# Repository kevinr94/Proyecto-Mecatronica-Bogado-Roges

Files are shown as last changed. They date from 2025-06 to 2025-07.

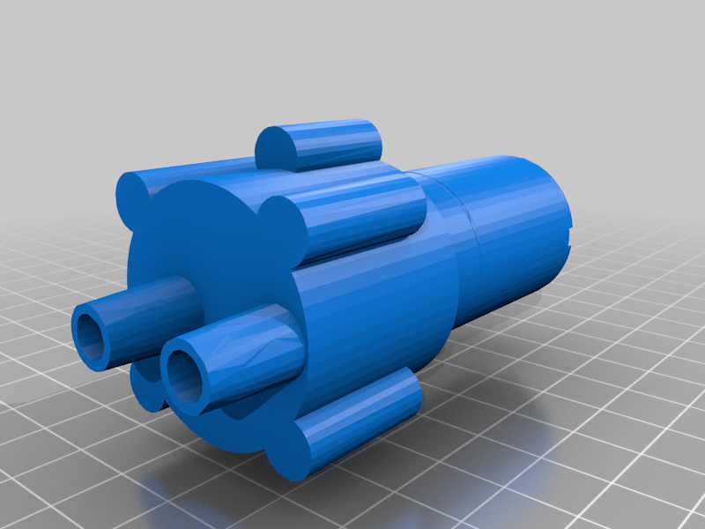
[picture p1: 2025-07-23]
Archivos 3D para imprimir/DC6-12V R385 Watter Pump - 3517927/images/9fce17ba2cacda95967c7b4c1f60414e.png

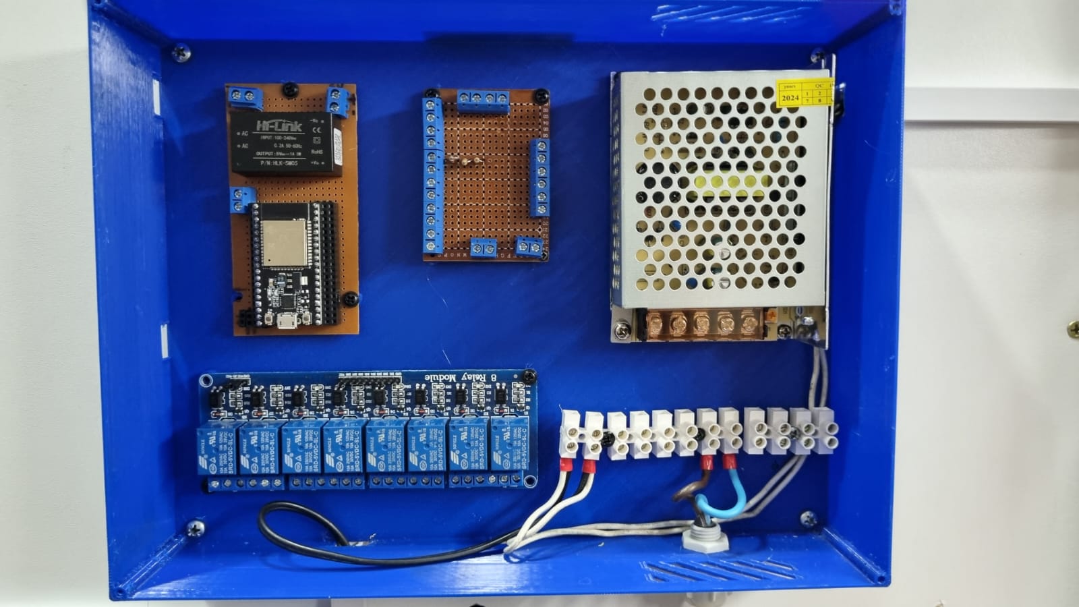
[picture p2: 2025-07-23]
Contenido multimedia/IMG-20250507-WA0041.jpg

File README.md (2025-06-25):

LOGO AZUL HORIZONTAL - fondo transparente
# Proyecto-Mecatronica-Bogado-Roges
Sistema de hidropnia, tipo raiz sumergida, automatizado. Con implementación de IA para la detección de enfermedades en plantas


### Autor
- Kevin Roges
- Bogado Jonathan
- Degree: Ingeniería Mecatrónica

## Introducción
Este proyecto se centra en la creación de un sistema automatizado de hidroponía tipo raiz sumergida. El objetivo es crear una solución eficiente y rentable para mantener la calidad del entorno en el que se cria la planta.

## Objetivos
- Diseñar e implementar un sistema automatizado.
- Garantizar una buen ambiente, como solución nutritiva, para el correcto crecimiento de la planta.
- Notificaciones mediante bot de Telegram.
- Implementación de IA para la detección de enfermedades mediante fotografías.

## Alcance
El proyecto abarcará el desarrollo del hardware y software necesario para el sistema. Incluye la integración de sensores, el control de pH y conductividad eléctrica de la solución, temperatura y humedad de cabina, temperatura de la solución y una interfaz de usuario interactiva. Ademas de los ciclos configurados de recirculación e iluminación.

## Resumen
El proyecto del sistema de hidroponia automatizado tiene como objetivo proporcionar una solución confiable para los entusiastas y profesionales de la horticultura, como para aquellos ajenos a la profesión. Gracias a la implementación de los sensores mencionados anteriormente ser logra una automatización bastante sólida y confiable. La interfaz de usuario es sumamente amigable e intuitiva, lo que permite su configuración de manera muy sencilla. La implementación de este sistema garantiza el correcto crecimiento de las plantas y un entorno saludable para la misma

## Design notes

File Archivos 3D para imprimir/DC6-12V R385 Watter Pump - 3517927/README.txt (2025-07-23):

DC6-12V R385 Watter Pump by albaniac on Thingiverse: https://www.thingiverse.com/thing:3517927

Summary:
This thing was made with Tinkercad. Edit it online

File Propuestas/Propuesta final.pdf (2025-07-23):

## Proyecto en Ingeniería Mecatrónica

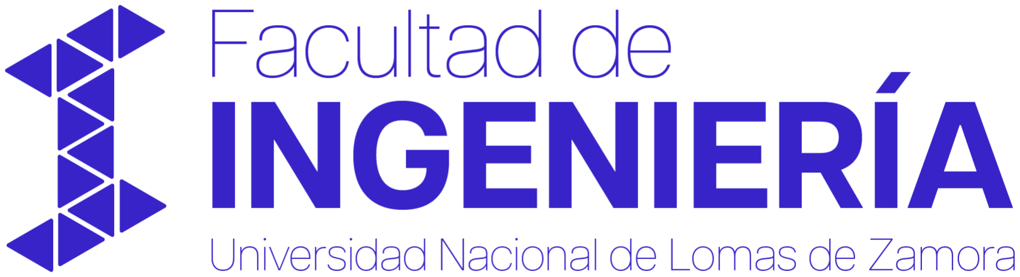
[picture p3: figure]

## Sistema Hidropónico automatizado con IA

Integrantes:
BOGADO Jonatan Emanuel
ROGES Kevin

Propuesta Final

1°C 2025

1

Facultad de Ingeniería
Universidad Nacional de Lomas de Zamora

## Índice

Nuestra motivación | 3
Proyecto | 4
Detalle de los pines a utilizar | 6
Costos del prototipo: | 7
Cronograma de trabajo | 8
Links | 11

Proyecto de Ingeniería Mecatrónica - 2

## Nuestra motivación

El proyecto seleccionado es un sistema automatizado de hidroponía con uso de IA para la detección de fallas.
Cada vez, la práctica de huertas caseras aumenta. Siendo la hidroponía, la de mayor popularidad.
La hidroponía es un método utilizado para cultivar plantas usando disoluciones minerales en vez de suelo agrícola. Al carecer de este, existen múltiples configuraciones y sistemas que permiten adaptarlos en múltiples espacios. A nivel doméstico, desde una habitación a un balcón.
La gran ventaja de estos sistemas es que logran disminuir los tiempos de cosecha considerablemente, siendo 30 días para una lechuga mientras que en un sistema tradicional como el cosechar sobre tierra, son aproximadamente 45-50 días.
La propuesta de nuestro grupo es armar un sistema, denominado raíz sumergida, en el cual, esta, se encuentra sumergida en una solución nutritiva. Se utilizará una bomba recirculadora, para airear esta solución y mediante el uso de bombas de diafragma se dosificará los nutrientes necesarios, para mantener los niveles correctos de conductividad eléctrica en las distintas etapas de crecimiento, y ajustar los niveles de pH también, según los niveles correctos en cada etapa de crecimiento.
Además incorpora un mecanismo que modificara la altura de la lámpara, esto permite modificar la cantidad de luz que recibe la planta en las distintas etapas de crecimiento
También se incorporará una cámara que, mediante IA, analizará el estado de la planta. Esto se realizará mediante fotografías cada 6 hs. Este proyecto se realizará en su totalidad, a una escala reducida, y se utilizará un contenedor previamente fabricado, apto para esta aplicación.

Proyecto de Ingeniería Mecatrónica - 3

## Proyecto

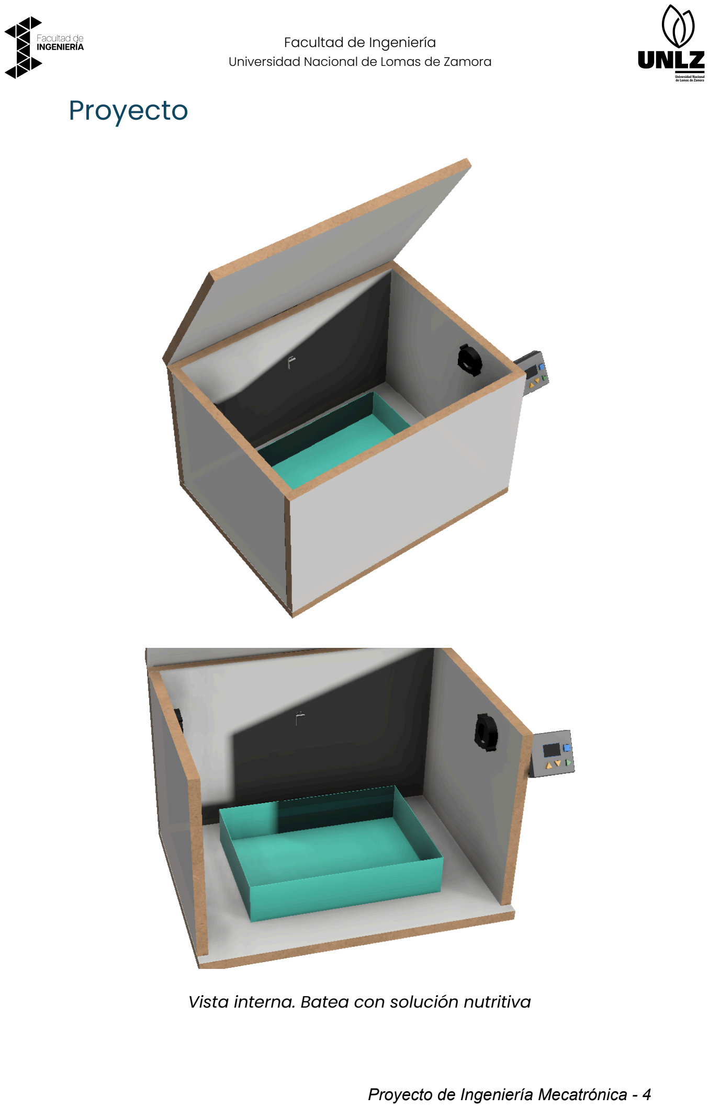
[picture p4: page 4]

Vista interna. Batea con solución nutritiva

Proyecto de Ingeniería Mecatrónica - 4

Partiendo de las recomendaciones brindadas por especialistas en el tema, nuestro sistema cuenta con el siguiente diagrama de flujo

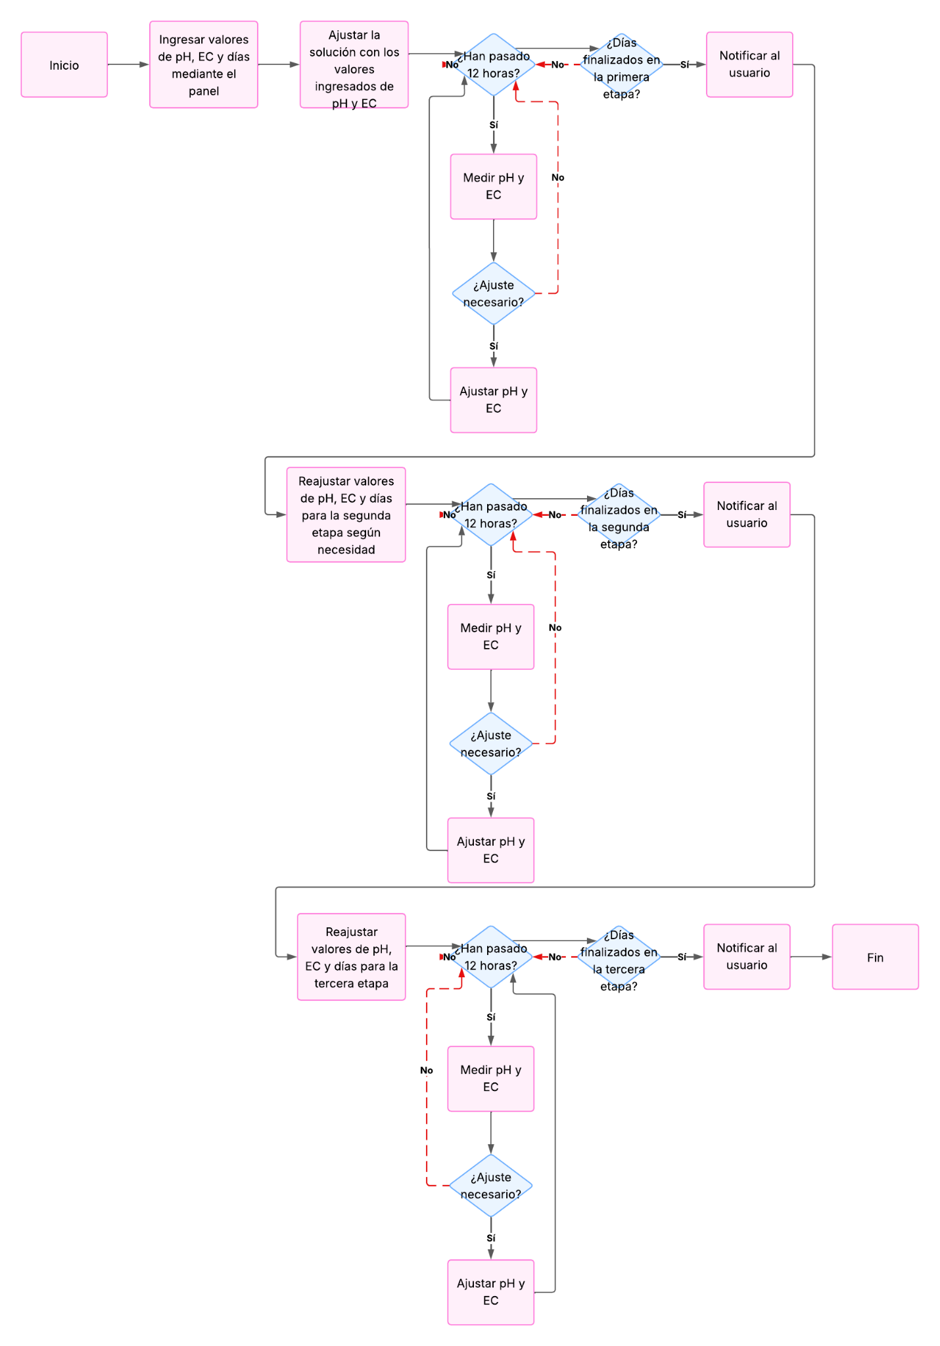
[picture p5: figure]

Proyecto de Ingeniería Mecatrónica - 5

## Detalle de los pines a utilizar

El sistema maestro de la máquina consta de lo siguientes componentes:

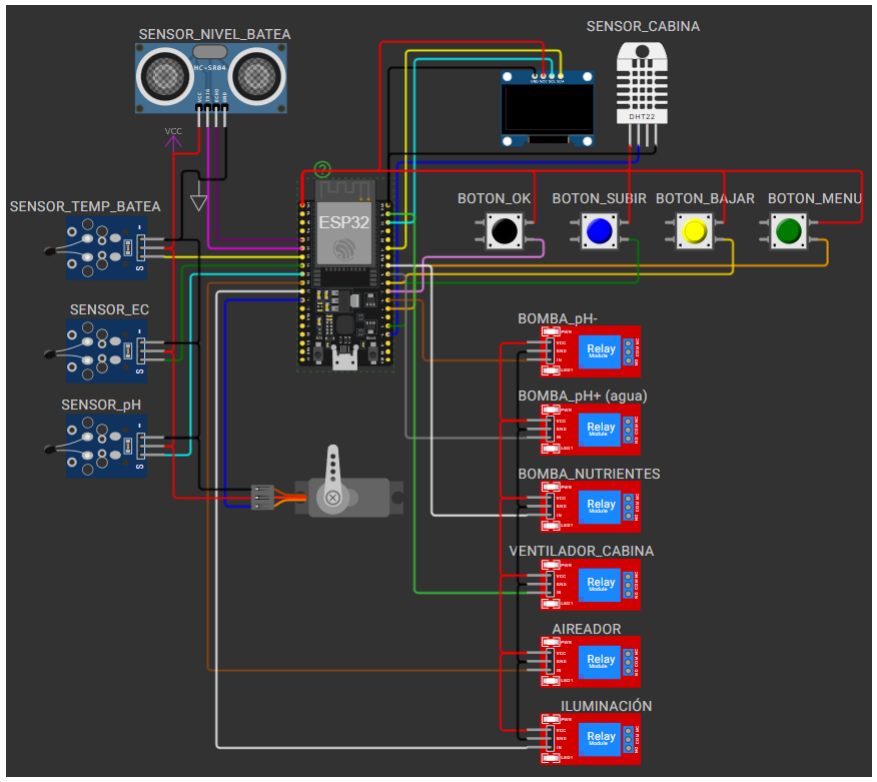
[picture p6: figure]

Por otra parte, el sistema integrado para procesar la IA consta de los siguientes componentes:

Proyecto de Ingeniería Mecatrónica - 6

## Costos del prototipo:

Descripción del Producto | Cantidad

Precio
Unitario C.U.uSd

Proveedo
r
Contenedor Plástico 10 L | 1 | 5990 | 5,48

Supermer
cado
Carrefour

Lampara Panel Led Indoor Cultivo 50
W Full Spectrum | 1 | 29.132 | 26,62

Mercado
Libre

Display Oled 0.96 Azul Amarillo 128x64
I2c Ssd1306 | 1 | 14519 | 13,25

Mercado
Libre
Cable Micro Usb | 1 | 10999 | 10,08

Supermer
cado
Coto
ESP32S | 2 | 20443,99 | 37,48

Mercado
Libre

Placa Base Mother Screw Shield
Nodemcu Esp32 Wroom 38 Pines | 1 | 18567,99 | 17,02

Mercado
Libre

Modulo Sensor De Calidad De Agua
Tds Sonda Analogico Arduino | 1 | 28442,99 | 26,07

Mercado
Libre

Modulo Y Sensor De Ph-4502c Para
Jardin Fermentacion Arduino | 1 | 51157 | 46,89

Mercado
Libre

Sensor De Temperatura Sumergible
Ds18b20 Arduino Todomicro | 1 | 11799,99 | 10,82

Mercado
Libre

Esp32 Cam Ov2640 + Placa Base
Programador Esp32-cam-mb | 1 | 31843,99 | 29,13

Mercado
Libre

Bomba De Agua Sumergible Sobo Wp
3200 60cm 300l/h 5w Fuente | 1 | 18292,99 | 16,71

Mercado
Libre

Reductor de Ph Ácido Fosfórico - 60
cc | 1 | 4.251,00 | 3,88

Mercado
Libre
Recortes melamina espesor 18 mm | 1 | 24.500 | 22,36 | Easy

Mini Servo Tower Pro Mg90 1.8kg
Servomotor Engranaje Arduino | 1 | 5840 | 5,33

Mercado
Libre
Impresiones 3D - Canastos, soporte
Display | 1 | 60000 | 54,77 | Anter 3D
Turbina Cooler Fan Extractor 220v
Ruleman 4 Pulgadas 120x38m | 2 | 19468 | 35,53
Esponja suave 1 u. | 1 | 1990 | 1,82

Mercado
Libre
Semilla Lechuga Mantecosa | 1 | 1199 | 1,1

Proyecto de Ingeniería Mecatrónica - 7

Módulo De Potencia 8 Vías Salida A
Rele Compatible C/arduino | 1 | 28441,19 | 25,96

Mercado
Libre

Bornera Divisible Resistente P/cable
2,5mm x 5 unidades | 1 | 18621,99 | 16,99

Mercado
Libre
Presupuesto total: [$] | 386878,12
Presupuesto total: [u$d] | 480,30

Los plazos de entrega existentes para compras realizadas en mercado libre de estos puntuales productos tiene un plazo de 1 a 3 días para la entrega. Las entregas se encuentran siendo entregadas dentro del plazo de las primeras 24 hs en los días laborales (excluyendo los días domingos y feriados).

## Cronograma de trabajo

Proyecto de Ingeniería Mecatrónica - 8

Facultad de Ingeniería
Universidad Nacional de Lomas de Zamora

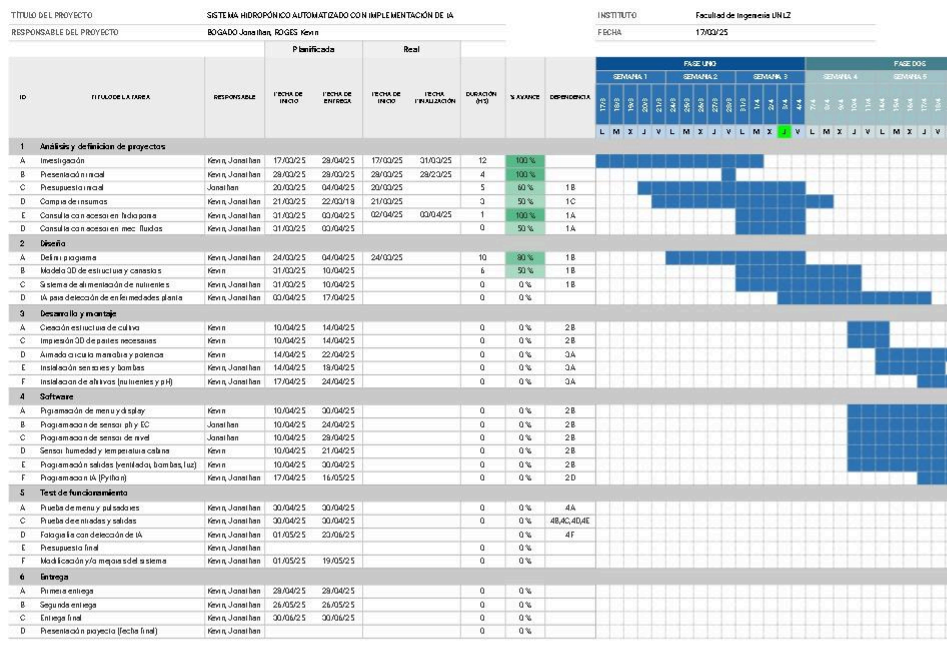
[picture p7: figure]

Proyecto de Ingeniería Mecatrónica - 9

Facultad de Ingeniería
Universidad Nacional de Lomas de Zamora

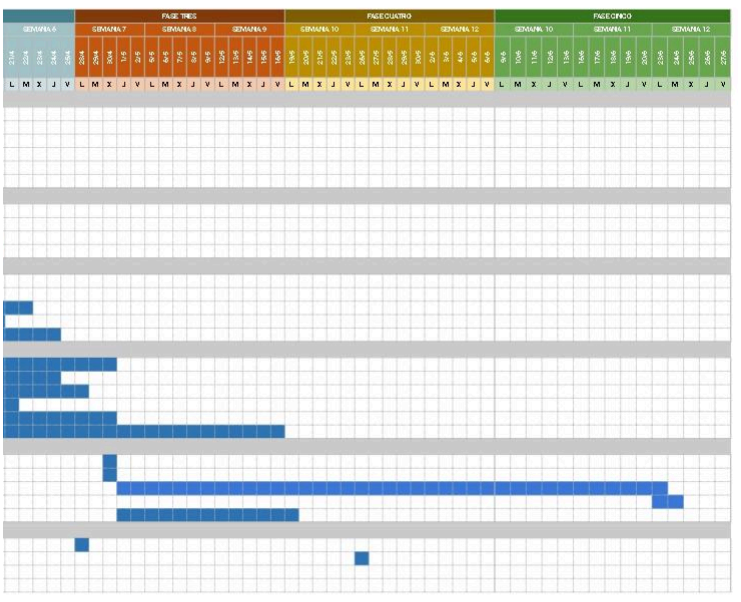
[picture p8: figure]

Proyecto de Ingeniería Mecatrónica - 10

## Links

- Detalles de pines del ESP principal. https://wokwi.com/projects/427135613235984385
- Diagrama de Gantt.
https://docs.google.com/spreadsheets/d/1WJwwtmo1ZOmqnn9Zxp-8Kr7q29bAdxEQrcd8iaJ9JY4/edit?usp=sharing

Proyecto de Ingeniería Mecatrónica - 11

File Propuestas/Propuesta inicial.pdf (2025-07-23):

## Proyecto en Ingeniería Mecatrónica


## Sistema Hidropónico automatizado con IA

Integrantes:
BOGADO Jonatan Emanuel
ROGES Kevin

1°C 2025

El proyecto seleccionado es un sistema automatizado de hidroponía con uso de IA para la detección de fallas.
Cada vez, la práctica de huertas caseras aumenta. Siendo la hidroponía, la de mayor popularidad.
La hidroponía es un método utilizado para cultivar plantas usando disoluciones minerales en vez de suelo agrícola. Al carecer de este, existen múltiples configuraciones y sistemas que permiten adaptarlos en múltiples espacios. A nivel doméstico, desde una habitación a un balcón.
La gran ventaja de estos sistemas es que logran disminuir los tiempos de cosecha considerablemente, siendo 30 días para una lechuga mientras que en un sistema tradicional como el cosechar sobre tierra, son aproximadamente 45-50 días.
La propuesta de nuestro grupo es armar un sistema, denominado raíz sumergida, en el cual, esta, se encuentra sumergida en una solución nutritiva. Se utilizará una bomba recirculadora, para airear esta solución y mediante el uso de bombas de diafragma se dosificará los nutrientes necesarios, para mantener los niveles correctos de conductividad eléctrica en las distintas etapas de crecimiento, y ajustar los niveles de pH también, según los niveles correctos en cada etapa de crecimiento.
Además incorpora un mecanismo que modificara la altura de la lámpara, esto permite modificar la cantidad de luz que recibe la planta en las distintas etapas de crecimiento
También se incorporará una cámara que, mediante IA, analizará el estado de la planta. Esto se realizará mediante fotografías cada 6 hs.
Este proyecto se realizará en su totalidad, a una escala reducida, y se utilizará un contenedor previamente fabricado, apto para esta aplicación.
Las consultas para realizar y las materias correspondientes:
- Química: Etapa donde se realizará los ajustes de pH y EC (conductividad eléctrica).
o ¿Se pueden realizar sobre el recipiente donde se sumergen las raíces?
o ¿Es conveniente hacer los ajustes en un recipiente pulmón y de este recircular a la batea?
- ¿Cada cuanto se recomienda revisar los niveles de pH de la solución nutritiva?
- ¿Cada cuanto tiempo se debe oxigenar la solución para aumentar el crecimiento de frutas y verduras?

Proyecto de Ingeniería Mecatrónica

- Mecánica de los fluidos: Implementación de bombas
o ¿Conviene el uso de bombas dosificadoras para cada solución (pH-, pH+, nutrientes)?
o ¿Se puede aprovechar el efecto Venturi, generado por la bomba recirculadora, para alimentar con cada solución mediante electroválvulas?
o ¿Alguno de los métodos, mencionados anteriormente, me garantizan una mejor homogeneización?

Proyecto de Ingeniería Mecatrónica

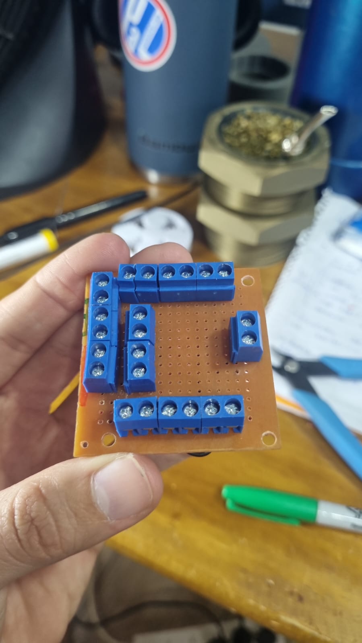
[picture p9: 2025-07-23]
Contenido multimedia/IMG-20250723-WA0023.jpg

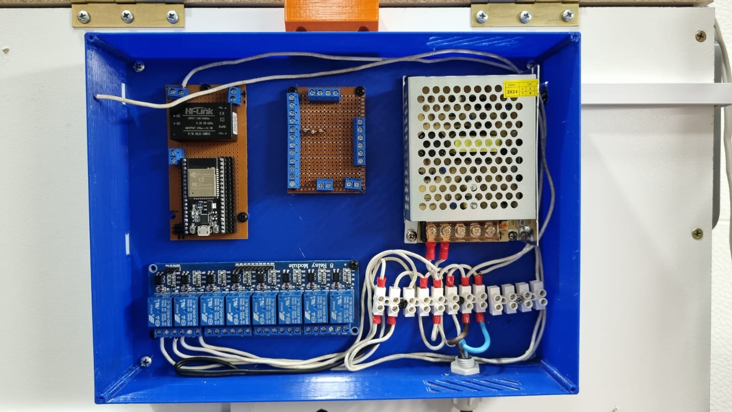
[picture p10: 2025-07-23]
Contenido multimedia/IMG-20250507-WA0042.jpg

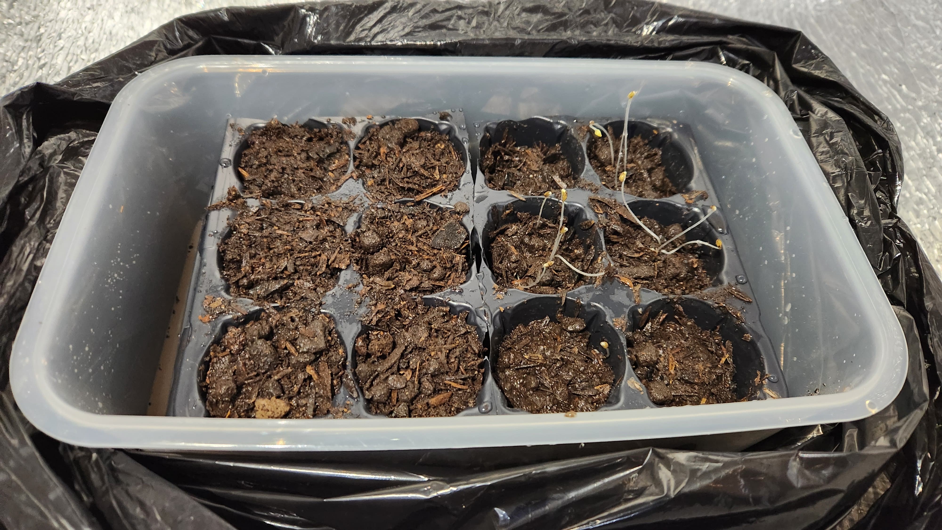
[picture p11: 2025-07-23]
Contenido multimedia/Imagen de WhatsApp 2025-07-23 a las 09.27.22_f90e9b1c.jpg

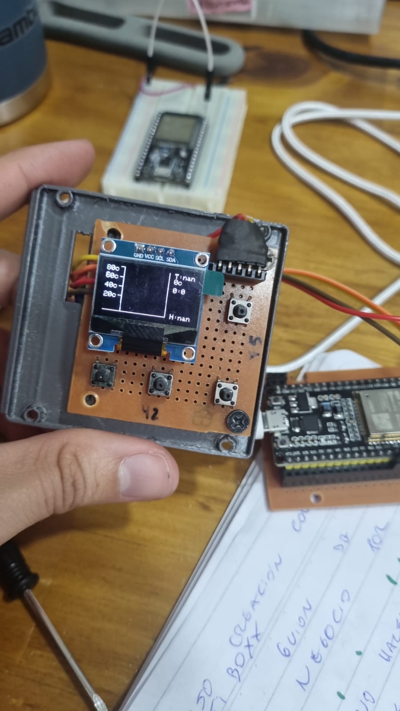
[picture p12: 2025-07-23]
Contenido multimedia/IMG-20250723-WA0022.jpg

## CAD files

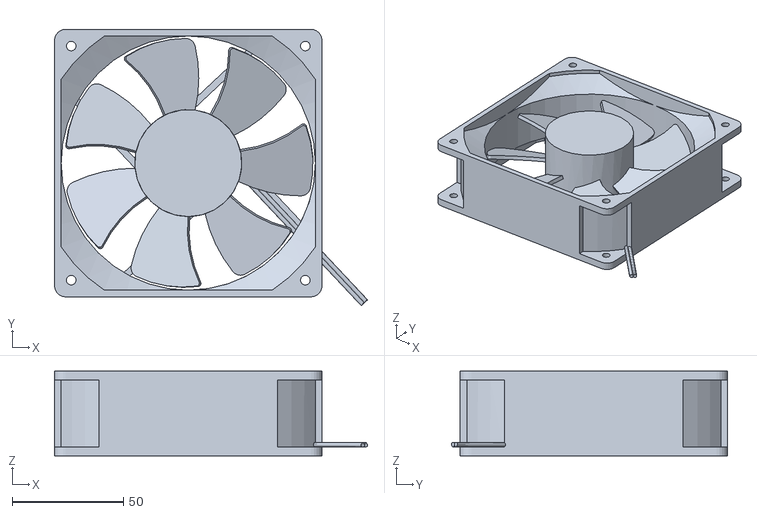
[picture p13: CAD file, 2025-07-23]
Archivos 3D para imprimir/161361850-21-fan_pmd1212pmb1-a__2__gn/fan_pmd1212pmb1-a__2__gn.stl
140.4 x 123.9 x 38.0

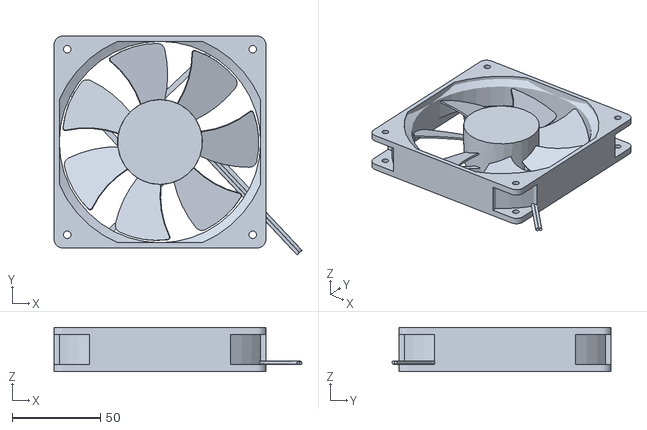
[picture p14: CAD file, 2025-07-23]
Archivos 3D para imprimir/161365758-21-fan_pmd1212ptb1-a__2__gn/fan_pmd1212ptb1-a__2__gn.stl
140.4 x 123.9 x 25.0

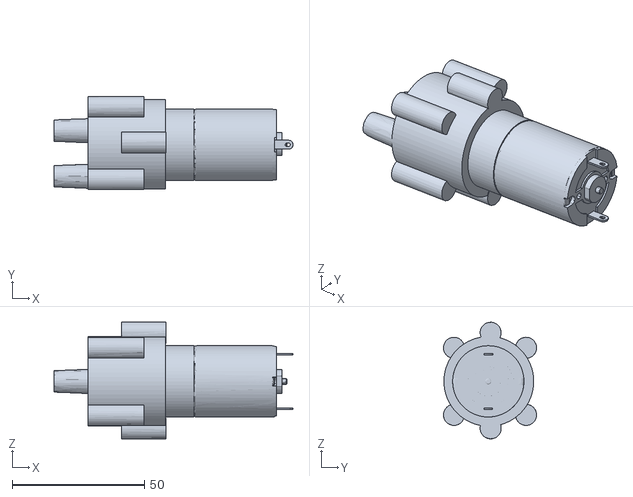
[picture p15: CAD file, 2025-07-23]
Archivos 3D para imprimir/DC6-12V R385 Watter Pump - 3517927/files/dc6-12v_r385.stl
90.5 x 35.3 x 44.2

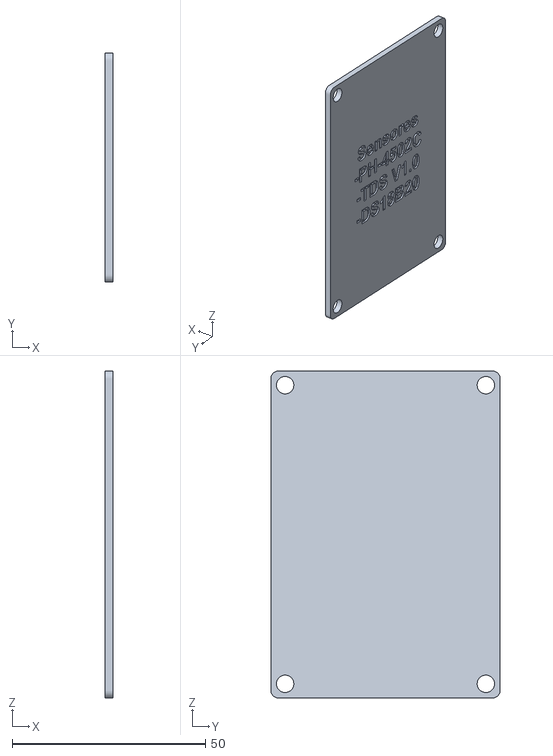
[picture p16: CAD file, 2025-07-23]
Archivos 3D para imprimir/Tapa carcasa sensores.stl
2.00 x 59.3 x 84.5

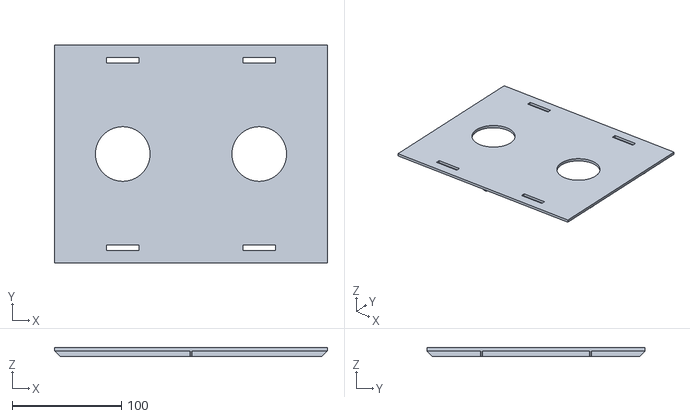
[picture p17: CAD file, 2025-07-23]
Archivos 3D para imprimir/Base macetas.stl
250.0 x 200.0 x 8.00

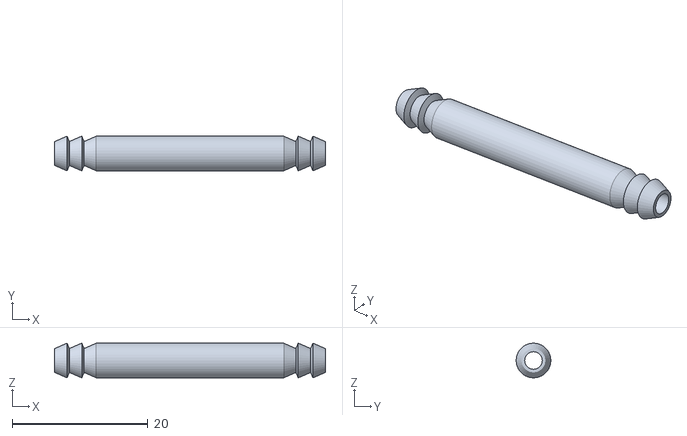
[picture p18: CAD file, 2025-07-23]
Archivos 3D para imprimir/Union manguera 6 mm.stl
40.0 x 5.13 x 5.13

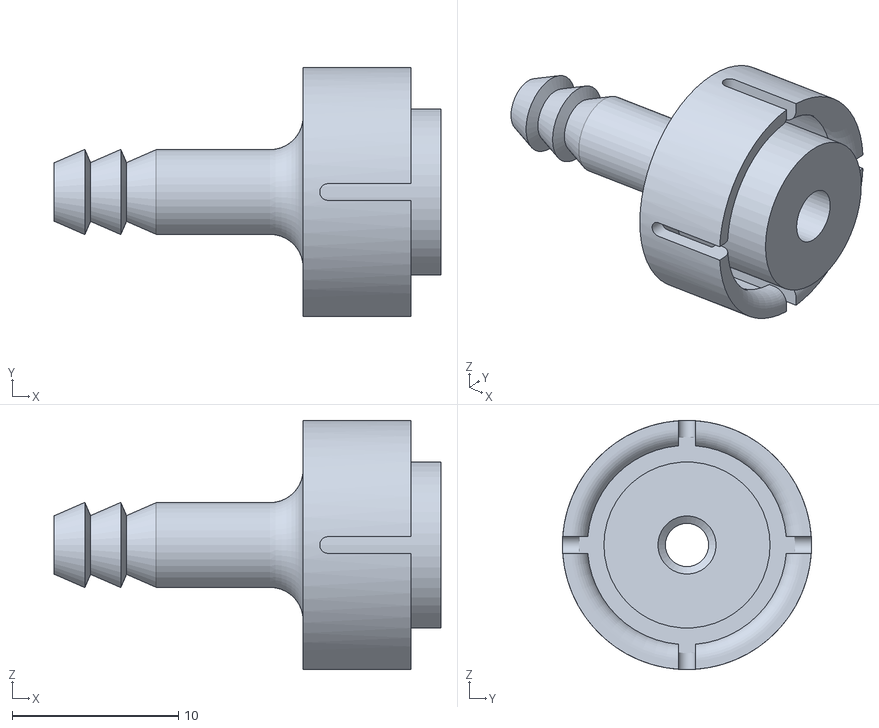
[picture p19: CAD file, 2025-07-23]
Archivos 3D para imprimir/Raccord para EV.stl
23.3 x 15.0 x 15.0

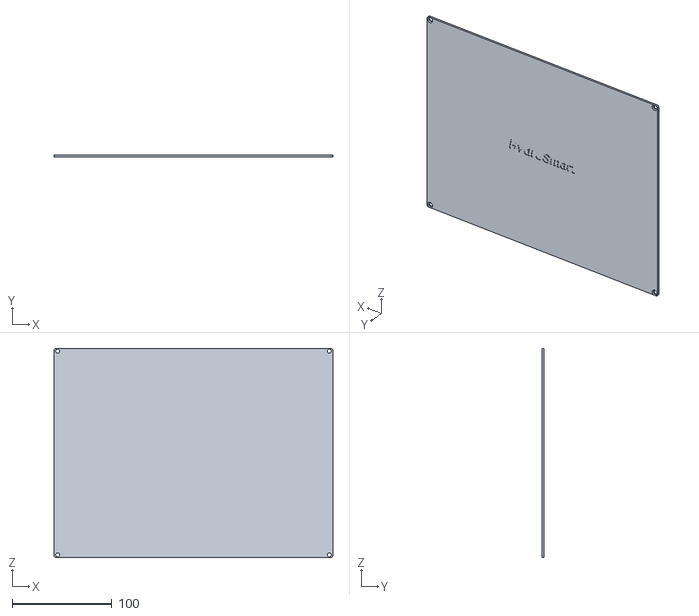
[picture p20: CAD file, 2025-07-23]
Archivos 3D para imprimir/Tapa.stl
280.0 x 2.00 x 210.0

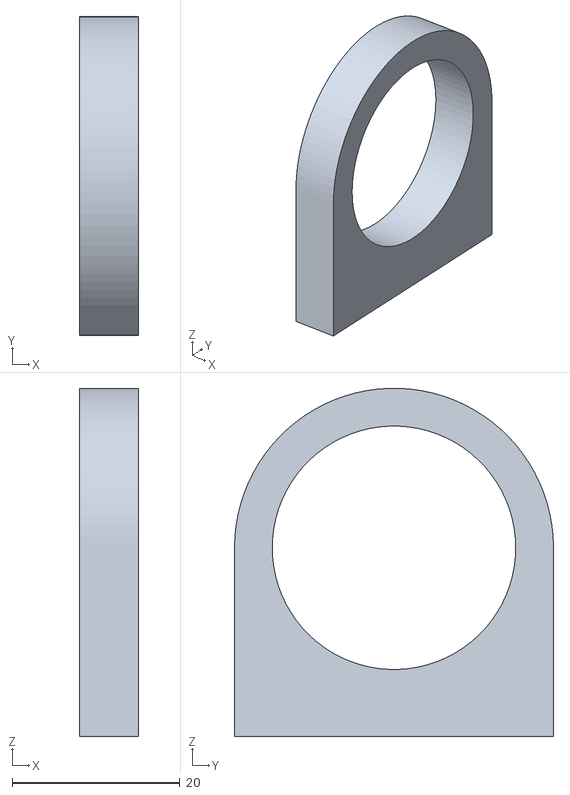
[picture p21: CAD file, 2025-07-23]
Archivos 3D para imprimir/Soporte eje servomotor.stl
7.00 x 38.0 x 41.5

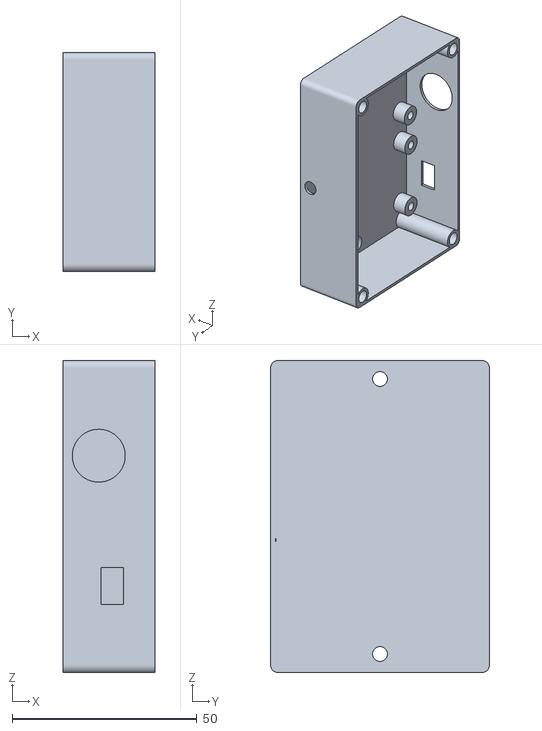
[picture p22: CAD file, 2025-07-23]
Archivos 3D para imprimir/Carcasa sensores.stl
25.0 x 59.3 x 84.5

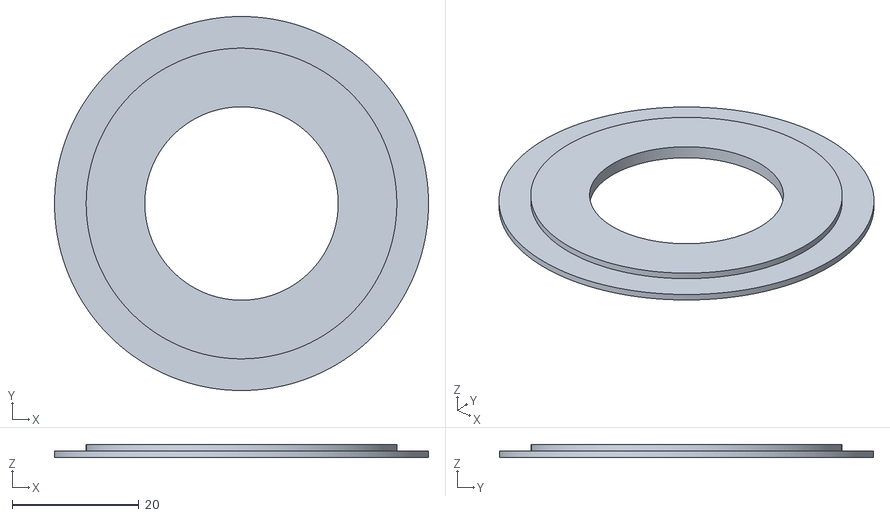
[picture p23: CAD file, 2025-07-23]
Archivos 3D para imprimir/arandela.stl
59.0 x 59.0 x 2.00

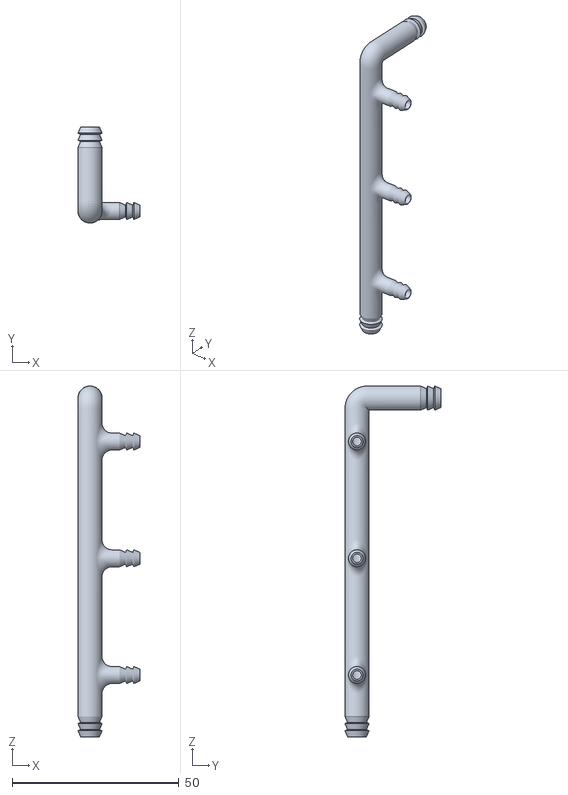
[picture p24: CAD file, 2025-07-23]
Archivos 3D para imprimir/Union electro-batea.stl
18.6 x 28.8 x 105.2

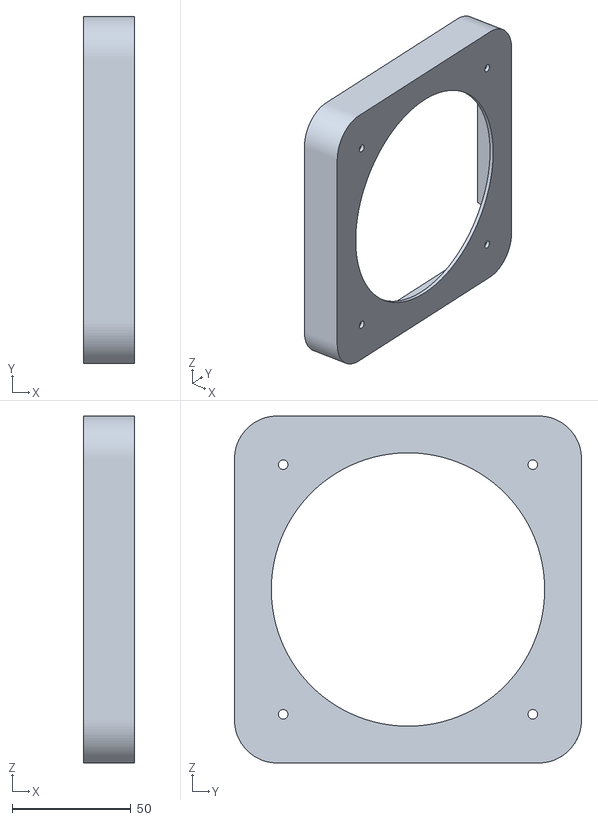
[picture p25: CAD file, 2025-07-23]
Archivos 3D para imprimir/Soporte trasero adicional cooler.stl
21.6 x 146.0 x 146.0

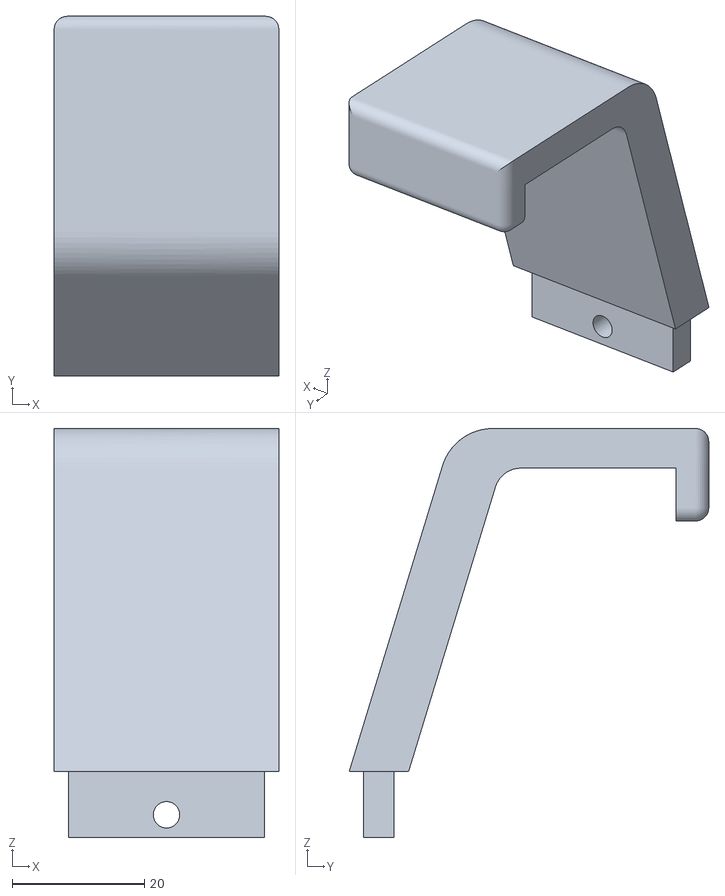
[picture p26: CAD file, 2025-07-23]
Archivos 3D para imprimir/Soporte base.stl
34.0 x 54.4 x 61.9

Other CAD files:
Archivos 3D para imprimir/Raccord para EV liso.stl
Archivos 3D para imprimir/Raccord para EV chico.stl
Archivos 3D para imprimir/Protector iluminacion.stl
Archivos 3D para imprimir/Soporte electroválvulas.stl
Archivos 3D para imprimir/Adaptador tablero.stl
Archivos 3D para imprimir/Carcasa base.stl
Archivos 3D para imprimir/Carcasa.stl
Archivos 3D para imprimir/Eje servomotor.stl
Archivos 3D para imprimir/Reparacion EV.stl
Archivos 3D para imprimir/Soporte cooler.stl
Archivos 3D para imprimir/Soporte fan iluminacion.stl
Archivos 3D para imprimir/Soporte servomotor.stl
Archivos 3D para imprimir/Soporte trasero cooler.stl
Archivos 3D para imprimir/Soporte ultrasonido.stl
Archivos 3D para imprimir/Soportes sensore.stl
Archivos 3D para imprimir/Soprote betea.stl
Archivos 3D para imprimir/Tablero electrico.stl
Archivos 3D para imprimir/racor.stl

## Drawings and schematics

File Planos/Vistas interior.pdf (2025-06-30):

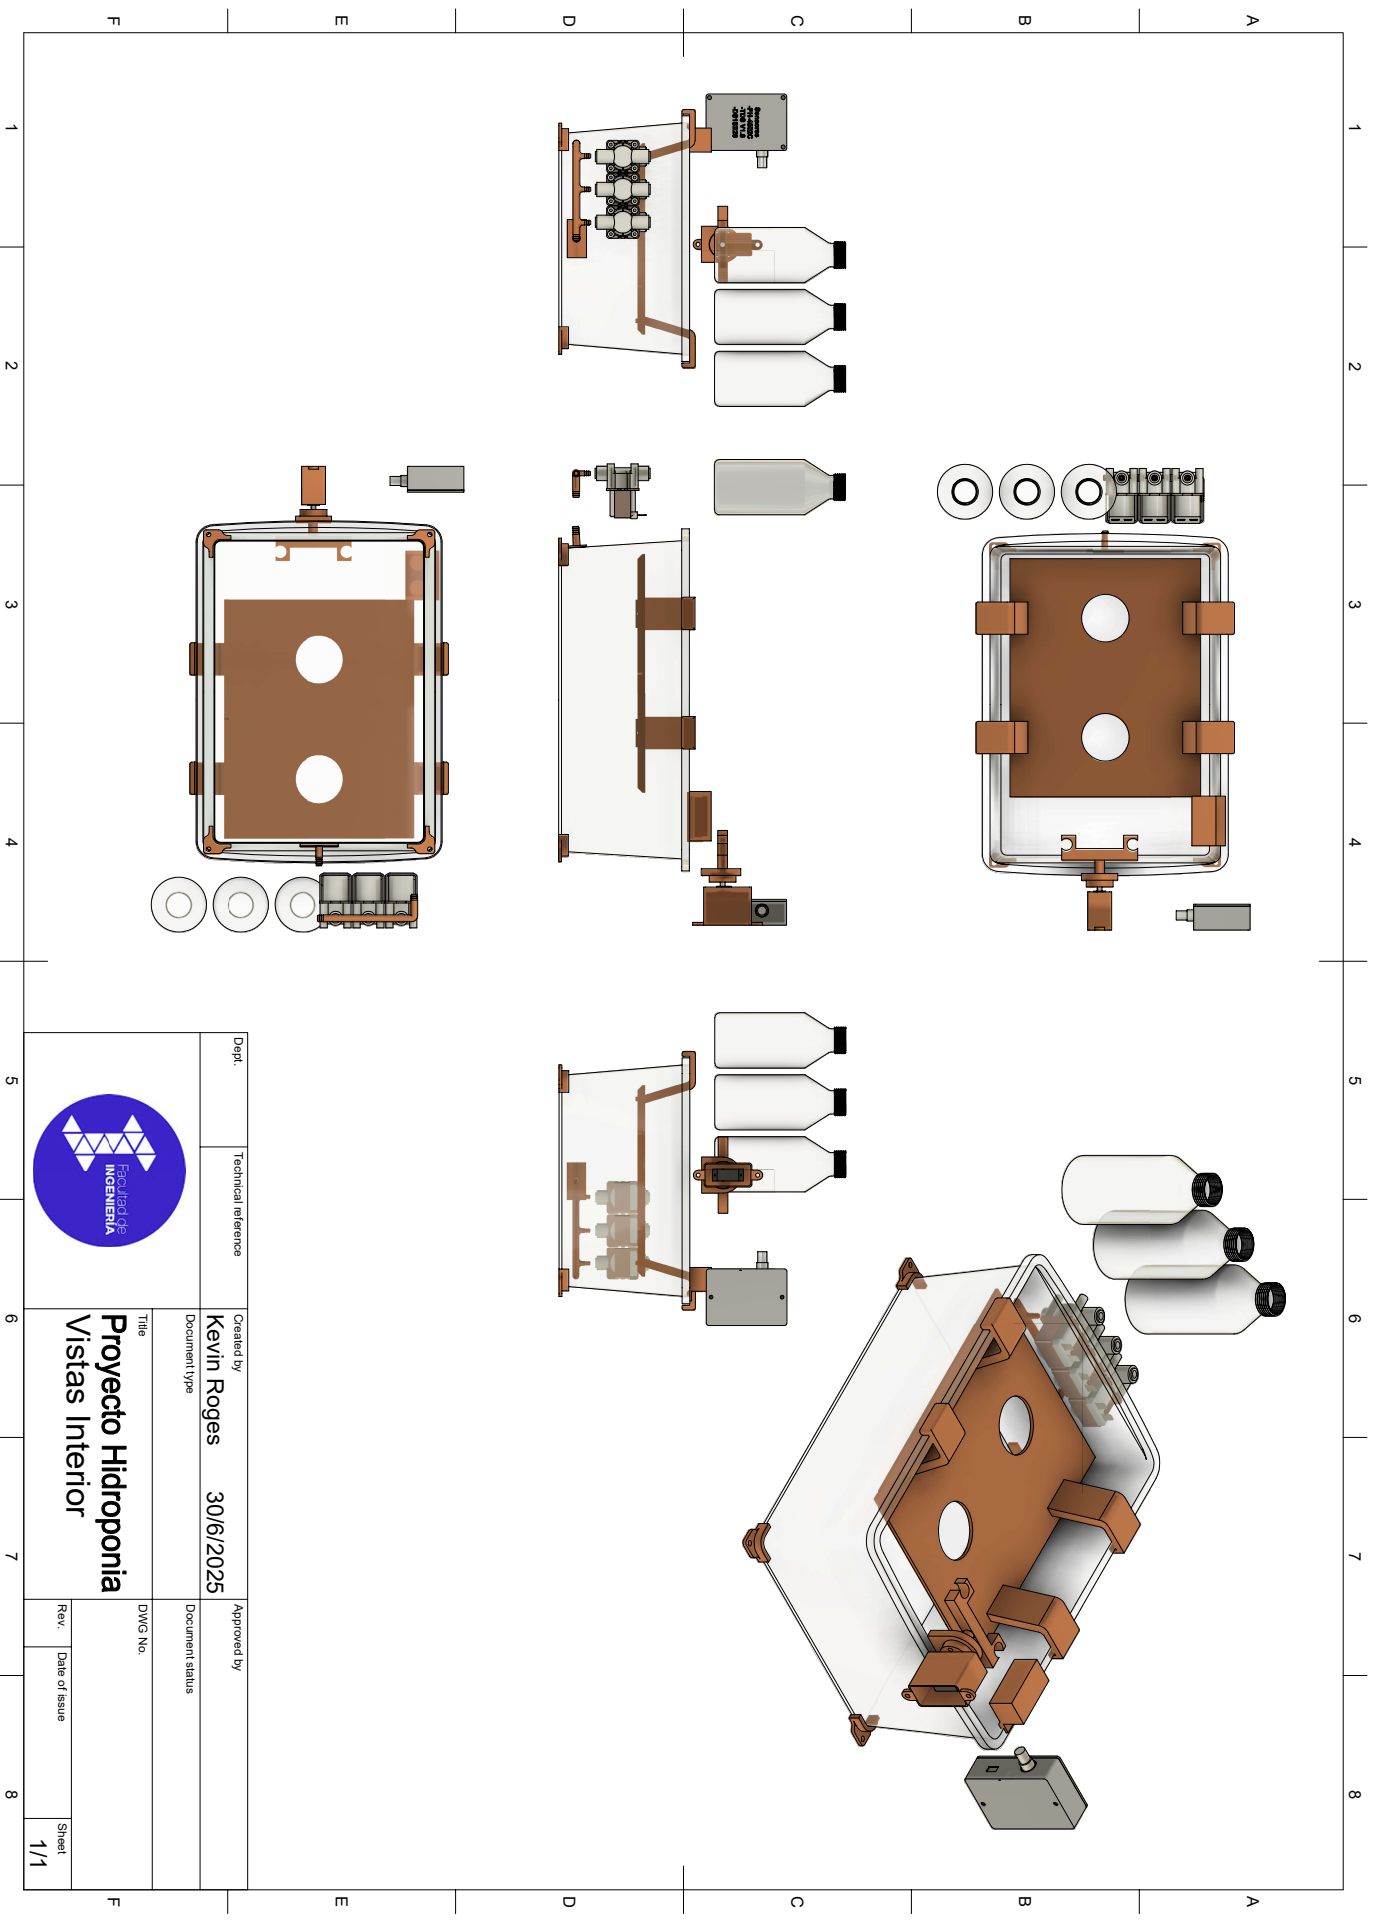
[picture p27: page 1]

1 A 2 3 4 5 6 7 8 1 2 3 4 5 6 7 8 FEDCB FEDCBA Dept. Technical reference Created by Approved by Title DWG No. Document type Document status Rev. Date of issue Sheet 30/6/2025 1/1 Vistas Interior Kevin Roges

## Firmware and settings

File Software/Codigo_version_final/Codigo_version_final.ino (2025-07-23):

#include "DHTesp.h"
#include <Wire.h>			
#include <Adafruit_GFX.h>		
#include <Adafruit_SSD1306.h>
#include <OneWire.h> 
#include <DallasTemperature.h>
#include <ESP32Servo.h>
#include "esp_task_wdt.h"
#include <WiFi.h>
#include <ArduinoJson.h>
#include <UniversalTelegramBot.h>
#include <WiFiClientSecure.h>
//Pulsadores del panel
#define menu_ok  12 //Botón para entrar a menu o volver
#define menu_up  14 // Botón para aumentar valores
#define menu_down  27 //Botón para decrecer valores
#define menu_config  26 //Botón confirmación
#define VENTILACION 2
#define ILUMINACION 0
#define BOMBA 4
#define EV1 16
#define EV2 17
#define EV3 5
#define NIVEL 19 // Sensor de nivel
#define activar_sensores 13
bool sensor_ph=false; //en false activa pH. En true activa TDS
//tds
#define TdsSensorPin 34
#define VREF 3.3              // analog reference voltage(Volt) of the ADC
#define SCOUNT  30            // sum of sample point
int analogBuffer[SCOUNT];     // store the analog value in the array, read from ADC
int analogBufferTemp[SCOUNT];
int analogBufferIndex = 0;
int copyIndex = 0;
float averageVoltage = 0;
float tdsValue = 0;
float temperature = 25;       // current temperature for compensation
// median filtering algorithm
int getMedianNum(int bArray[], int iFilterLen){
  int bTab[iFilterLen];
  for (byte i = 0; i<iFilterLen; i++)
  bTab[i] = bArray[i];
  int i, j, bTemp;
  for (j = 0; j < iFilterLen - 1; j++) {
    for (i = 0; i < iFilterLen - j - 1; i++) {
      if (bTab[i] > bTab[i + 1]) {
        bTemp = bTab[i];
        bTab[i] = bTab[i + 1];
        bTab[i + 1] = bTemp;
      }
    }
  }
  if ((iFilterLen & 1) > 0){
    bTemp = bTab[(iFilterLen - 1) / 2];
  }
  else {
    bTemp = (bTab[iFilterLen / 2] + bTab[iFilterLen / 2 - 1]) / 2;
  }
  return bTemp;
}
//tds
//ph
#define pHpin  35
#define VREF 3.3               // voltaje de referencia ADC ESP32
#define pH_SAMPLES 30          // cantidad de muestras a promediar
int pHBuffer[pH_SAMPLES];      // buffer circular
int pHBufferTemp[pH_SAMPLES];  // copia para filtrar
int pHIndex = 0;               // índice de inserción
float pH = 7.0;                // valor final de pH
float slope = -5.315;           // calibración (ajustar según tu sensor)
float offset = 21.87;          // calibración (ajustar según tu sensor)
int calcularMediana(int datos[], int cantidad) {
  int copiaDatos[cantidad];
  for (int i = 0; i < cantidad; i++) {
    copiaDatos[i] = datos[i];
  }

  for (int j = 0; j < cantidad - 1; j++) {
    for (int i = 0; i < cantidad - j - 1; i++) {
      if (copiaDatos[i] > copiaDatos[i + 1]) {
        int temp = copiaDatos[i];
        copiaDatos[i] = copiaDatos[i + 1];
        copiaDatos[i + 1] = temp;
      }
    }
  }

  if (cantidad % 2 == 1) {
    return copiaDatos[cantidad / 2];
  } else {
    return (copiaDatos[cantidad / 2] + copiaDatos[(cantidad / 2) - 1]) / 2;
  }
}
//ph
#define ANCHO 128  //Parametro de pantalla Oled	
#define ALTO 64	
#define OLED_RESET 4			
int menu = 0;
int menu2 = 0;
int menu3 = 0;
int etapa = 1; //identifi a numero de etapa
int dia_obj = 1; //cantidad de dias de etapa
float ph_min = 4.0;//pH minimo
float ph_max = 7.0; //pH maximo
int ec_min = 500; //ec min
int ec_max = 1500; //ec max
bool estadoVent = false;
bool estadoVentAnterior = false;
bool estadoIlum = false;
bool estadoIlumAnterior = false;
bool estadoBomba = false;
bool estadoEv1 = false;
bool estadoEv2 = false;
bool estadoEv3 = false;
bool estadoServo = false;
#define oneWireBus  23 //Sensor temperatura liquido
float temperatureC;
OneWire oneWire(oneWireBus);
DallasTemperature sensors(&oneWire);
Adafruit_SSD1306 display(ANCHO, ALTO);	
int pinDHT = 15; //Iniciamos sensor DHT22
DHTesp dht;
// Electroconductividad (EC) [milisiemens por centímetro (mS/cm)] y Sólidos Disueltos Totales (TDS) [ppm]
float ecPromedio = 0.0;
float tds = 0.0;
Servo miServo;  // crea el objeto servo
const int pinServo = 25; // Pin GPIO al que está conectado el servo
static unsigned long lastDebounceTime = 0;
unsigned long tiempoDebounce = 300; //tiempo debounce botones

//Parametros del programa
bool inicio_programa = false;
int dias_transcurridos = 0;
unsigned long inicioCicloMillis = 0;
unsigned long duracionBomba = 2UL * 60UL * 60UL * 1000UL; // 2 horas en milisegundos
unsigned long intervalo12h = 12UL * 60UL * 60UL * 1000UL; // 12 horas en milisegundos
unsigned long ultimoCicloMillis = 0;
bool cicloActivo = false;
bool ecListo = false;
bool phListo = false;
unsigned long tiempoInicioPrograma = 0;
bool primerInicio = true;
unsigned long tiempo_dia_anterior = 0;
const unsigned long INTERVALO_DIA = 24UL * 60UL * 60UL * 1000UL; // 24 hs en ms
//unsigned long duracionBomba = 10UL * 60UL * 1000UL; // 5 minutos VARIABLES DE PRUEBA
//unsigned long intervalo12h = 15UL * 60UL * 1000UL; // 15 minutos VARIABLES DE PRUEBA
//const unsigned long INTERVALO_DIA = 30UL * 60UL * 1000UL; // 30 minutos VARIABLES DE PRUEBA
static unsigned long tiempoInicioLuz = 0;  // <-- NUEVO
const unsigned long INTERVALO_LUZ_ENCENDIDA = 16UL * 60UL * 60UL * 1000UL; // 16 horas
unsigned long tiempoEsperaPH = 0;
unsigned long tiempoEsperaSegundaMedicion = 0;
bool esperaPHIniciada = false;
bool segundaMedicionHecha = false;
bool enEsperaSegundaMedicion = false;
bool segundaECListo = false;
bool segundaPHListo = false;
unsigned long tiempoEsperaPH_2 = 0;
bool aviso_medicion_ph;
bool aviso_ph_fin;
bool segundaMedicionECHecha = false;
bool segundaMedicionPHHecha = false;
//Variables de sensores pH y EC. Necesarias aca, para luego poder reinciiar
static unsigned long ultimaEjecucion1 = 0;
static unsigned long inicioInyeccion1 = 0;
static bool inyectando1 = false;
static bool esperando1 = false;
static int lecturasCorrectas1 = 0;
static unsigned long ultimaEjecucion = 0;
static unsigned long inicioInyeccion = 0;
static bool inyectando = false;
static bool esperando = false;
static int lecturasCorrectas = 0;
//
unsigned long ultimaLecturaTemp = 0;
bool esperandoTemperatura = false;
// wifi casa
const char* ssid = "MOVISTAR Wifi6";
const char* password = "Movistar827";

/*//WiFi FI-UNLZ
const char* ssid = "Comunidad-FIUNLZ";
const char* password = "#ingenieria2023";
*/
//WiFi celular
/*const char* ssid = "GalaxyS21FE";
const char* password = "uouk4373";
*/
// Initialize Telegram BOT
#define BOTtoken "7864124463:AAGqeX4AymXzyKB_yKku8ZIlFUbBW9uAJS4"  // el token de tu BOT, lo obtenemos de BotFather
#define CHAT_ID  "1430541964"
bool mensaje1, mensaje2, mensaje3, mensaje4, mensaje5, mensaje6, mensaje7, mensaje8, mensaje9, mensaje10, mensaje11;

WiFiClientSecure client;
UniversalTelegramBot bot(BOTtoken, client);
//Parámetros para manejar cola mensajes Telegram
#define MAX_COLA 10  // Cantidad máxima de mensajes en la cola
String colaMensajes[MAX_COLA];
int indiceInicio = 0;
int indiceFin = 0;
int cantidadMensajes = 0;
unsigned long ultimoEnvio = 0;
const unsigned long intervaloEnvio = 5000;  // 5 segundos entre mensajes


void setup() {
  pinMode(menu_ok, INPUT_PULLDOWN);
  pinMode(menu_up, INPUT_PULLDOWN);
  pinMode(menu_down, INPUT_PULLDOWN);
  pinMode(menu_config, INPUT_PULLDOWN);
  pinMode(NIVEL, INPUT_PULLUP);
  pinMode(VENTILACION, OUTPUT);
  pinMode(ILUMINACION, OUTPUT);
  pinMode(BOMBA, OUTPUT);
  pinMode(EV1, OUTPUT);
  pinMode(EV2, OUTPUT);
  pinMode(EV3, OUTPUT);
  digitalWrite(VENTILACION, HIGH);
  digitalWrite(ILUMINACION, HIGH);
  digitalWrite(BOMBA, HIGH);
  digitalWrite(EV1, HIGH);
  digitalWrite(EV2, HIGH);
  digitalWrite(EV3, HIGH);
  pinMode(TdsSensorPin,INPUT);
  miServo.attach(pinServo);
  pinMode(activar_sensores, OUTPUT);
  analogReadResolution(12);                // 12 bits → 0–4095
  analogSetPinAttenuation(pHpin, ADC_11db);      // rango 0–3.3 V
  analogSetPinAttenuation(TdsSensorPin, ADC_11db);
  sensors.begin();  // Iniciar sensor
  Wire.begin();
  Wire.setClock(100000);
  Serial.begin(115200);	
  display.begin(SSD1306_SWITCHCAPVCC, 0x3C);
  display.setTextSize(1);           
  display.setTextColor(SSD1306_WHITE);
  display.setCursor(10,40);
  display.display();
  //Inicializamos el dht
  dht.setup(pinDHT, DHTesp::DHT22);
  //iniciamos WiFi y bot Telegram
  initWiFi();
  encolarMensaje("✅ Hydro Smart iniciado");
  // Inicializa el watchdog para el task actual (loop)
  esp_task_wdt_config_t wdt_config = {
    .timeout_ms = 8000,     // 8 segundos
    .idle_core_mask = 1,    // núcleo 0
    .trigger_panic = true   // reinicia si no se alimenta
  };
  esp_reset_reason_t reason = esp_reset_reason();
  Serial.print("Motivo del último reset: ");
  Serial.println(reason);
  procesarColaTelegram(); //VER SI FUNCIONA BIEN ACA
  esp_task_wdt_init(&wdt_config);
  esp_task_wdt_add(NULL);  // Añade la tarea actual (loop)
}

void loop(){
  procesarColaTelegram();
  lecturaTemperatura(); 
  TempAndHumidity data = dht.getTempAndHumidity(); //Obtención de temperatura y humedad de DHT22
  relay_bomba();
  relay_ilum();
  relay_vent();
  relay_ev1();
  relay_ev2();
  relay_ev3();
  servo_sensor();
  lecturaTDS();
  lecturapH();
  lectura_sensores();
  display.clearDisplay();
  // Inicio del programa
if (inicio_programa == true) {
    if (dias_transcurridos <= dia_obj) {
      unsigned long tiempoActual = millis();
      if (primerInicio || (tiempoActual - ultimoCicloMillis >= intervalo12h)) {// Iniciar un nuevo ciclo de 2 horas
        inicioCicloMillis = tiempoActual;
        ultimoCicloMillis = tiempoActual;
        cicloActivo = true;
        estadoBomba = true;
        ecListo = false;
        phListo = false;
        primerInicio = false;
        tiempoInicioLuz = millis(); // para control de luz (pero no prenderá inmediatamente)
        esperaPHIniciada = false;
        segundaMedicionHecha = false;
        enEsperaSegundaMedicion = false;
        segundaMedicionECHecha = false;
        segundaMedicionPHHecha = false;
        mensaje1 = true, mensaje2 = true, mensaje3 = true, mensaje4 = true, mensaje5 = true, mensaje6 = true, mensaje7 = true, mensaje8 = true, mensaje9 = true, mensaje10 = true, mensaje11 = true;
      }
      // --- Control de iluminación (enciende 1h después de inicio del ciclo) ---
      if (millis() - tiempoInicioLuz >= 3600000UL && millis() - tiempoInicioLuz <= 3600000UL + INTERVALO_LUZ_ENCENDIDA) {
        estadoIlum = true;
      } else {
        estadoIlum = false;
      }
      if (estadoIlum != estadoIlumAnterior) {
        if (estadoIlum) {
          encolarMensaje("Iluminación encendida 💡");
        } else {
          encolarMensaje("Iluminación apagada");
        }
        estadoIlumAnterior = estadoIlum;
      }

      if (data.humidity >= 50) {
        estadoVent = true;
      } else {
        estadoVent = false;
      }

      if (estadoVent != estadoVentAnterior) {
        if (estadoVent) {
          encolarMensaje("Ventilación encendida 🍃");
        } else {
          encolarMensaje("Ventilación apagada");
        }
        estadoVentAnterior = estadoVent;
      }

      if (cicloActivo) { //Ciclo de recirculacion bomba y ajuste pH-EC
        if (tiempoActual - inicioCicloMillis <= duracionBomba) {
          // Mientras dure el ciclo de 2 horas
          lectura_sensores();  // Gestiona el relay de sensores
          if(mensaje1){
            encolarMensaje("Inicio de ciclo recirculación. Medición y ajuste EC");
            mensaje1 = false;
          }
          if (!ecListo) {
            sensor_ph = false; // Apaga PH, prende EC
            lecturaTDS();      // Lee EC
            ajuste_ec();       // Ajuste de EC
            if (aviso_medicion_ph) {
              ecListo = true;
              estadoServo = true;
              encolarMensaje("EC correcto: "+String(tdsValue));
              aviso_medicion_ph = false;
              esperaPHIniciada = true;
              tiempoEsperaPH = millis(); // comienza espera de estabilización de pH
              sensor_ph = true;  // Apaga EC, prende PH
              lecturapH();       // Lee PH
              Serial.println("EC bien");
            }
          } 
          else if (!phListo) {
            if (esperaPHIniciada && millis() - tiempoEsperaPH >= 120000UL) { // 2 minutos de espera
              ajuste_pH();       // Ajuste de PH
              if(mensaje3){
                encolarMensaje("Ajuste y medición pH");
                mensaje3 = false;
              }
              if (aviso_ph_fin) {
                phListo = true;
                encolarMensaje("pH bien: "+String(pH));
                aviso_ph_fin = false;
                estadoServo = false;
                // Preparar segunda medición
                enEsperaSegundaMedicion = true;
                tiempoEsperaSegundaMedicion = millis();
                segundaMedicionECHecha = false;
                segundaMedicionPHHecha = false;
                segundaMedicionHecha = false;
                sensor_ph = false;
                Serial.println("pH bien");
                // ⚠️ REINICIO DE VARIABLES DEL AJUSTE EC
                reiniciar_sensores();
              }
            }
          }
          else if (enEsperaSegundaMedicion && !segundaMedicionHecha) {
            // Esperar 30 minutos antes de segunda medición EC
            if (!segundaMedicionECHecha && millis() - tiempoEsperaSegundaMedicion >= 1800000UL) { // 30 minutos
              sensor_ph = false; // Apaga PH, prende EC
              lecturaTDS();      // Lee EC
              ajuste_ec();       // Ajuste de EC
              if(mensaje4){
                encolarMensaje("Iniciando segunda medición y ajuste EC");
                mensaje4 = false;
              }
              if (aviso_medicion_ph) {
                encolarMensaje("EC bien: "+String(tdsValue));
                aviso_medicion_ph = false;
                estadoServo = true;
                esperaPHIniciada = true;
                tiempoEsperaPH = millis();
                sensor_ph = true; // Apaga EC, prende PH
                lecturapH();
                Serial.println("Lectura de pH iniciada");
                segundaMedicionECHecha = true;
              }
            }
            // Esperar 2 minutos para estabilizar pH antes de ajustar
            if (segundaMedicionECHecha && !segundaMedicionPHHecha && esperaPHIniciada && millis() - tiempoEsperaPH >= 120000UL) {
              ajuste_pH();
              if(mensaje5){
                encolarMensaje("Segundo ajuste y medición pH");
                mensaje5 = false;
              }
              if (aviso_ph_fin) {
                encolarMensaje("pH bien: "+String(pH));
                sensor_ph = false;
                estadoServo = false;
                aviso_ph_fin = false;
                segundaMedicionPHHecha = true;
                segundaMedicionHecha = true;
                Serial.println("Segunda medición: pH completada");
              }
            }
          }
        } else {
          // Fin del ciclo de 2 horas
          mensaje6 = true;
          if(mensaje6){
            encolarMensaje("Finzalición del ciclo recirculación");
            mensaje6 = false;
          }
          estadoBomba = false;
          estadoServo = false;
          cicloActivo = false;
        }
      }
      // Conteo de días cada 24 hs
      if (millis() - tiempo_dia_anterior >= INTERVALO_DIA) {
        dias_transcurridos++;
        tiempo_dia_anterior = millis();
        tiempoInicioLuz = millis(); // Reiniciar ciclo de iluminación
        if(mensaje11){
          encolarMensaje("Días transcurridos: "+String(dias_transcurridos));
          mensaje11 = false;
        }
      }
    } else {
      // Programa finalizado
      inicio_programa = false;
      estadoBomba = false;
      estadoServo = false;
      estadoIlum = false;
      estadoVent = false;
      estadoEv1 = false;
      estadoEv2 = false;
      estadoEv3 = false;
    }
    
  }
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
